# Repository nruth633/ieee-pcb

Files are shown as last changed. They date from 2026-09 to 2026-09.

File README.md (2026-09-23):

# IEEE LED Cube Board

KiCad design for one slice of the LED matrix cube that the University of Denver IEEE
chapter is building as a group project. Three daisy-chained 74HCT595 shift registers drive
24 MMBT3904 low-side switches, which gives eight RGB columns from a five-wire bus (CLK,
DATA, LATCH, BLANK, GND).

Write-up: https://nruth633.github.io/projects/ieee-cube.html

Open `ieee.kicad_pro` in KiCad 10.

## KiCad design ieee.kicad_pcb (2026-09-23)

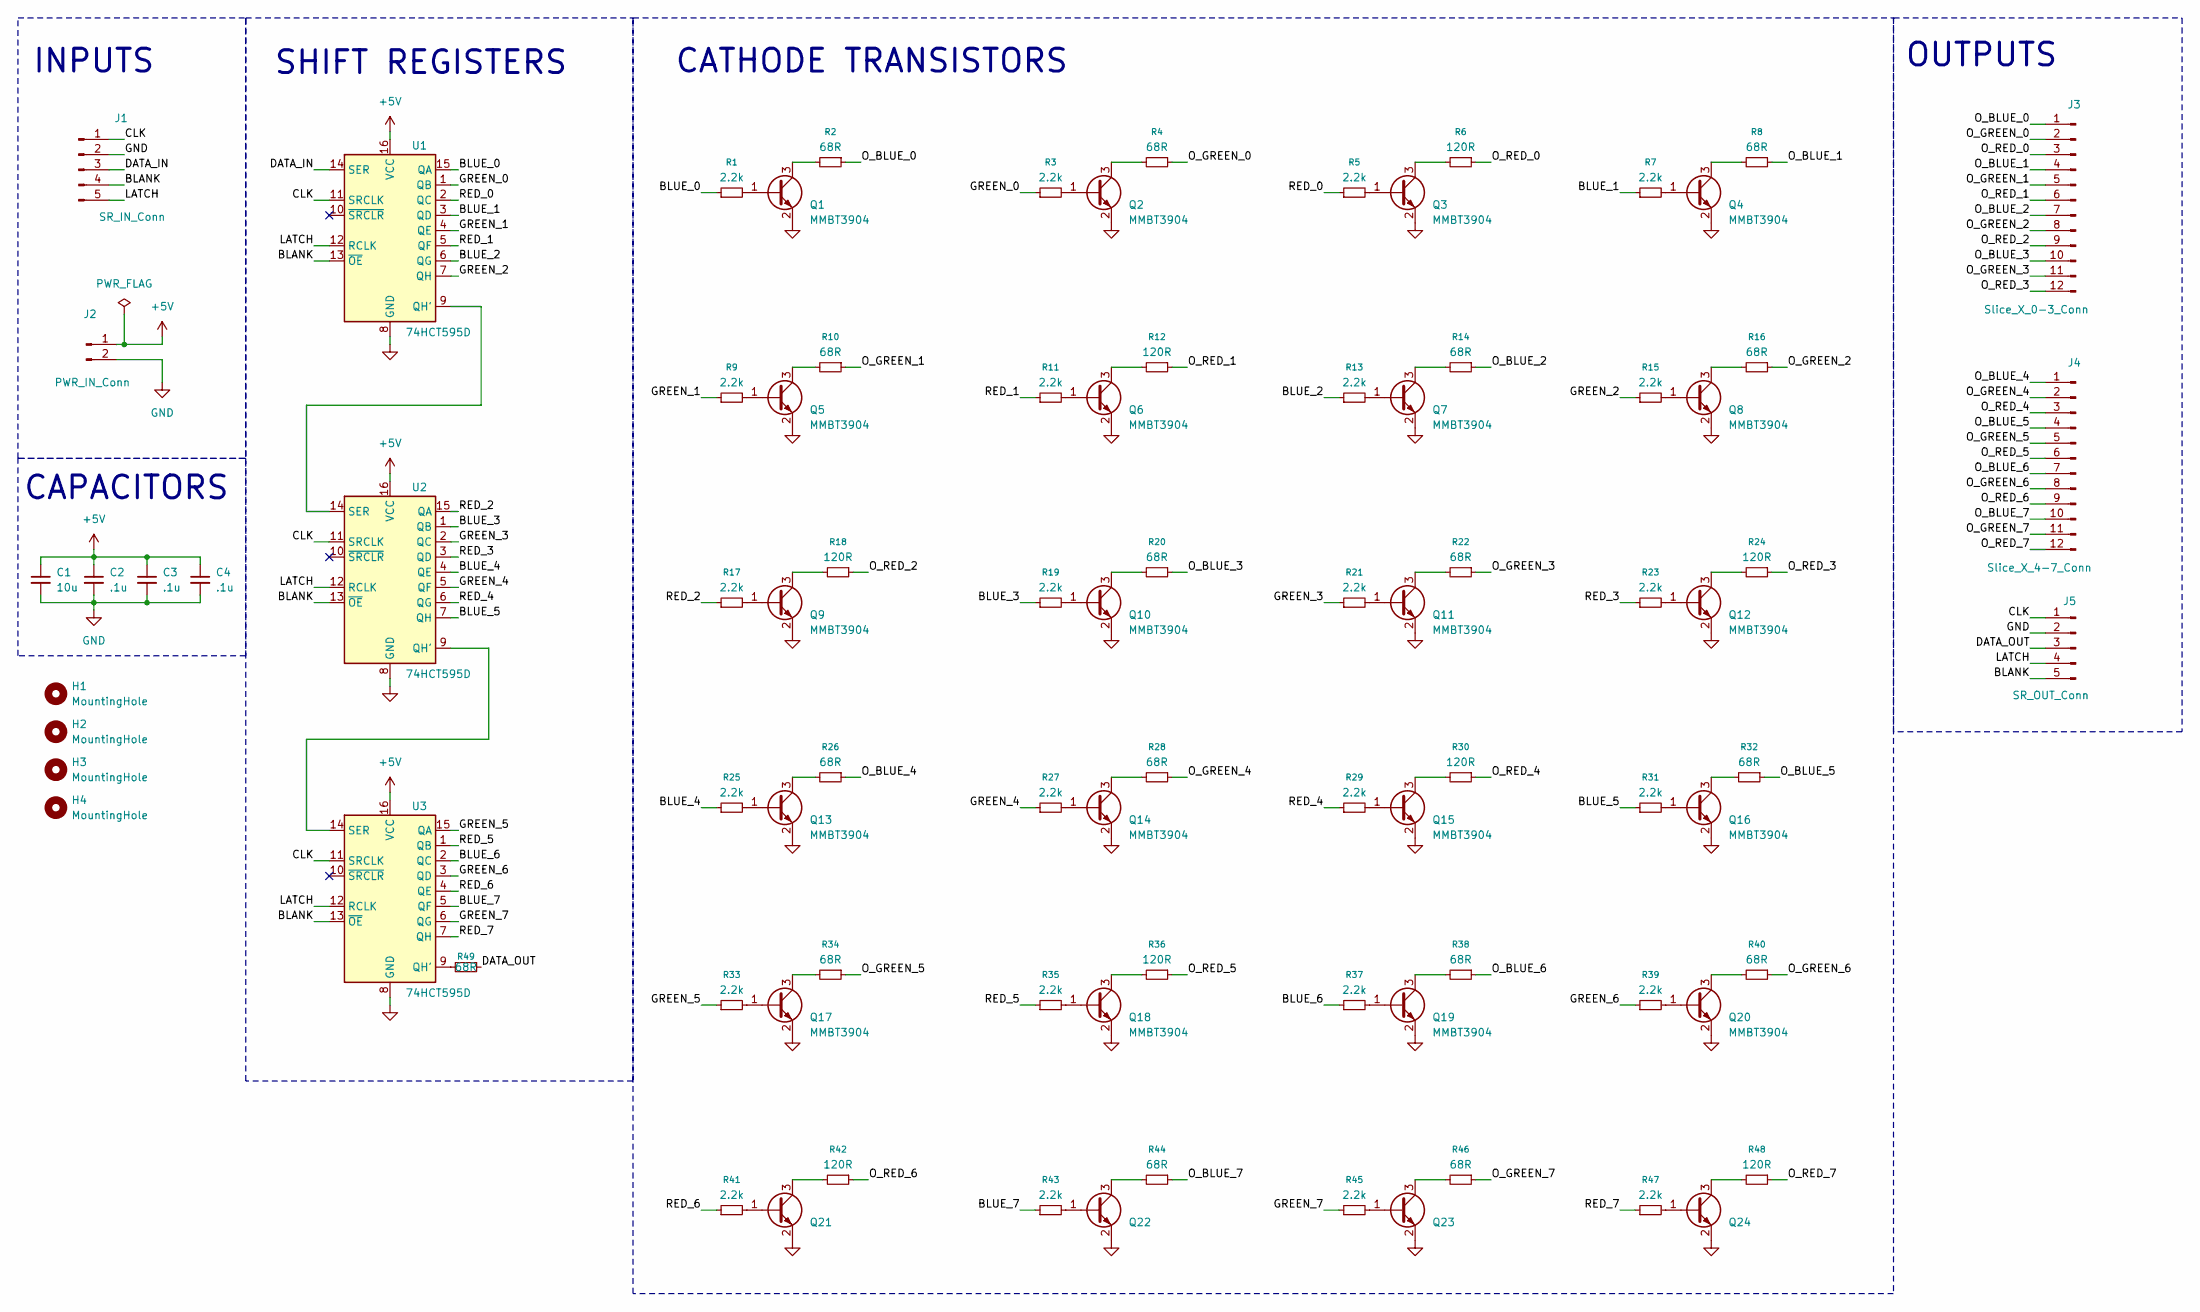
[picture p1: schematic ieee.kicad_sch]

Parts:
C1: 10u; C_0805_2012Metric_Pad1.18x1.45mm_HandSolder; Mfr # MCASL21GBB7106KTNA01
C2, C3, C4: .1u; C_0805_2012Metric_Pad1.18x1.45mm_HandSolder; Mfr # KAF21BR71H104JM
H1, H2, H3, H4: MountingHole; MountingHole_3.2mm_M3
J1: SR_IN_Conn; JST_PH_B5B-PH-K_1x05_P2.00mm_Vertical; Mfr # B5B-PH-K-S(LF)(SN)
J2: PWR_IN_Conn; JST_XH_B2B-XH-A_1x02_P2.50mm_Vertical; Mfr # B2B-XH-A
J3: Slice_X_0-3_Conn; JST_PH_B12B-PH-K_1x12_P2.00mm_Vertical; Mfr # B12B-PH-K-S
J4: Slice_X_4-7_Conn; JST_PH_B12B-PH-K_1x12_P2.00mm_Vertical; Mfr # B12B-PH-K-S
J5: SR_OUT_Conn; JST_PH_B5B-PH-K_1x05_P2.00mm_Vertical; Mfr # B5B-PH-K-S(LF)(SN)
Q1, Q2, Q3, Q4, Q5, Q6, Q7, Q8, Q9, Q10, Q11, Q12, Q13, Q14, Q15, Q16, Q17, Q18, Q19, Q20, Q21, Q22, Q23, Q24: MMBT3904; SOT-23; Mfr # 750-MMBT3904-G
R1, R3, R5, R7, R9, R11, R13, R15, R17, R19, R21, R23, R25, R27, R29, R31, R33, R35, R37, R39, R41, R43, R45, R47: 2.2k; R_0805_2012Metric_Pad1.20x1.40mm_HandSolder; Mfr # 0805W8J0222T5E
R2, R4, R8, R10, R14, R16, R20, R22, R26, R28, R32, R34, R38, R40, R44, R46, R49: 68R; R_0805_2012Metric_Pad1.20x1.40mm_HandSolder; Mfr # 0805W8J0680T5E
R6, R12, R18, R24, R30, R36, R42, R48: 120R; R_0805_2012Metric_Pad1.20x1.40mm_HandSolder; Mfr # RT0805FRE13120RL
U1, U2, U3: 74HCT595D; SOIC-16_3.9x9.9mm_P1.27mm; Mfr # 74HCT595D,118

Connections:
+5V: C1.1, C2.1, C3.1, C4.1, J2.1, U1.16 (VCC), U2.16 (VCC), U3.16 (VCC)
/BLANK: J1.4, J5.5, U1.13 (~OE), U2.13 (~OE), U3.13 (~OE)
/BLUE_0: R1.1, U1.15 (QA)
/BLUE_1: R7.1, U1.3 (QD)
/BLUE_2: R13.1, U1.6 (QG)
/BLUE_3: R19.1, U2.1 (QB)
/BLUE_4: R25.1, U2.4 (QE)
/BLUE_5: R31.1, U2.7 (QH)
/BLUE_6: R37.1, U3.2 (QC)
/BLUE_7: R43.1, U3.5 (QF)
/CLK: J1.1, J5.1, U1.11 (SRCLK), U2.11 (SRCLK), U3.11 (SRCLK)
/DATA_IN: J1.3, U1.14 (SER)
/DATA_OUT: J5.3, R49.1
/GREEN_0: R3.1, U1.1 (QB)
/GREEN_1: R9.1, U1.4 (QE)
/GREEN_2: R15.1, U1.7 (QH)
/GREEN_3: R21.1, U2.2 (QC)
/GREEN_4: R27.1, U2.5 (QF)
/GREEN_5: R33.1, U3.15 (QA)
/GREEN_6: R39.1, U3.3 (QD)
/GREEN_7: R45.1, U3.6 (QG)
/LATCH: J1.5, J5.4, U1.12 (RCLK), U2.12 (RCLK), U3.12 (RCLK)
/O_BLUE_0: J3.1, R2.1
/O_BLUE_1: J3.4, R8.1
/O_BLUE_2: J3.7, R14.1
/O_BLUE_3: J3.10, R20.1
/O_BLUE_4: J4.1, R26.1
/O_BLUE_5: J4.4, R32.1
/O_BLUE_6: J4.7, R38.1
/O_BLUE_7: J4.10, R44.1
/O_GREEN_0: J3.2, R4.1
/O_GREEN_1: J3.5, R10.1
/O_GREEN_2: J3.8, R16.1
/O_GREEN_3: J3.11, R22.1
/O_GREEN_4: J4.2, R28.1
/O_GREEN_5: J4.5, R34.1
/O_GREEN_6: J4.8, R40.1
/O_GREEN_7: J4.11, R46.1
/O_RED_0: J3.3, R6.1
/O_RED_1: J3.6, R12.1
/O_RED_2: J3.9, R18.1
/O_RED_3: J3.12, R24.1
/O_RED_4: J4.3, R30.1
/O_RED_5: J4.6, R36.1
/O_RED_6: J4.9, R42.1
/O_RED_7: J4.12, R48.1
/RED_0: R5.1, U1.2 (QC)
/RED_1: R11.1, U1.5 (QF)
/RED_2: R17.1, U2.15 (QA)
/RED_3: R23.1, U2.3 (QD)
/RED_4: R29.1, U2.6 (QG)
/RED_5: R35.1, U3.1 (QB)
/RED_6: R41.1, U3.4 (QE)
/RED_7: R47.1, U3.7 (QH)
GND: C1.2, C2.2, C3.2, C4.2, J1.2, J2.2, J5.2, Q1.2 (E), Q2.2 (E), Q3.2 (E), Q4.2 (E), Q5.2 (E), Q6.2 (E), Q7.2 (E), Q8.2 (E), Q9.2 (E), Q10.2 (E), Q11.2 (E), Q12.2 (E), Q13.2 (E), Q14.2 (E), Q15.2 (E), Q16.2 (E), Q17.2 (E), Q18.2 (E), Q19.2 (E), Q20.2 (E), Q21.2 (E), Q22.2 (E), Q23.2 (E), Q24.2 (E), U1.8 (GND), U2.8 (GND), U3.8 (GND)
unnamed: Q1.1 (B), R1.2
unnamed: Q1.3 (C), R2.2
unnamed: Q2.1 (B), R3.2
unnamed: Q2.3 (C), R4.2
unnamed: Q3.1 (B), R5.2
unnamed: Q3.3 (C), R6.2
unnamed: Q4.1 (B), R7.2
unnamed: Q4.3 (C), R8.2
unnamed: Q5.1 (B), R9.2
unnamed: Q5.3 (C), R10.2
unnamed: Q6.1 (B), R11.2
unnamed: Q6.3 (C), R12.2
unnamed: Q7.1 (B), R13.2
unnamed: Q7.3 (C), R14.2
unnamed: Q8.1 (B), R15.2
unnamed: Q8.3 (C), R16.2
unnamed: Q9.1 (B), R17.2
unnamed: Q9.3 (C), R18.2
unnamed: Q10.1 (B), R19.2
unnamed: Q10.3 (C), R20.2
unnamed: Q11.1 (B), R21.2
unnamed: Q11.3 (C), R22.2
unnamed: Q12.1 (B), R23.2
unnamed: Q12.3 (C), R24.2
unnamed: Q13.1 (B), R25.2
unnamed: Q13.3 (C), R26.2
unnamed: Q14.1 (B), R27.2
unnamed: Q14.3 (C), R28.2
unnamed: Q15.1 (B), R29.2
unnamed: Q15.3 (C), R30.2
unnamed: Q16.1 (B), R31.2
unnamed: Q16.3 (C), R32.2
unnamed: Q17.1 (B), R33.2
unnamed: Q17.3 (C), R34.2
unnamed: Q18.1 (B), R35.2
unnamed: Q18.3 (C), R36.2
unnamed: Q19.1 (B), R37.2
unnamed: Q19.3 (C), R38.2
unnamed: Q20.1 (B), R39.2
unnamed: Q20.3 (C), R40.2
unnamed: Q21.1 (B), R41.2
unnamed: Q21.3 (C), R42.2
unnamed: Q22.1 (B), R43.2
unnamed: Q22.3 (C), R44.2
unnamed: Q23.1 (B), R45.2
unnamed: Q23.3 (C), R46.2
unnamed: Q24.1 (B), R47.2
unnamed: Q24.3 (C), R48.2
unnamed: U1.9 (QH'), U2.14 (SER)
unnamed: U2.9 (QH'), U3.14 (SER)
unnamed: R49.2, U3.9 (QH')

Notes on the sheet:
INPUTS
CATHODE TRANSISTORS
SHIFT REGISTERS
OUTPUTS
CAPACITORS

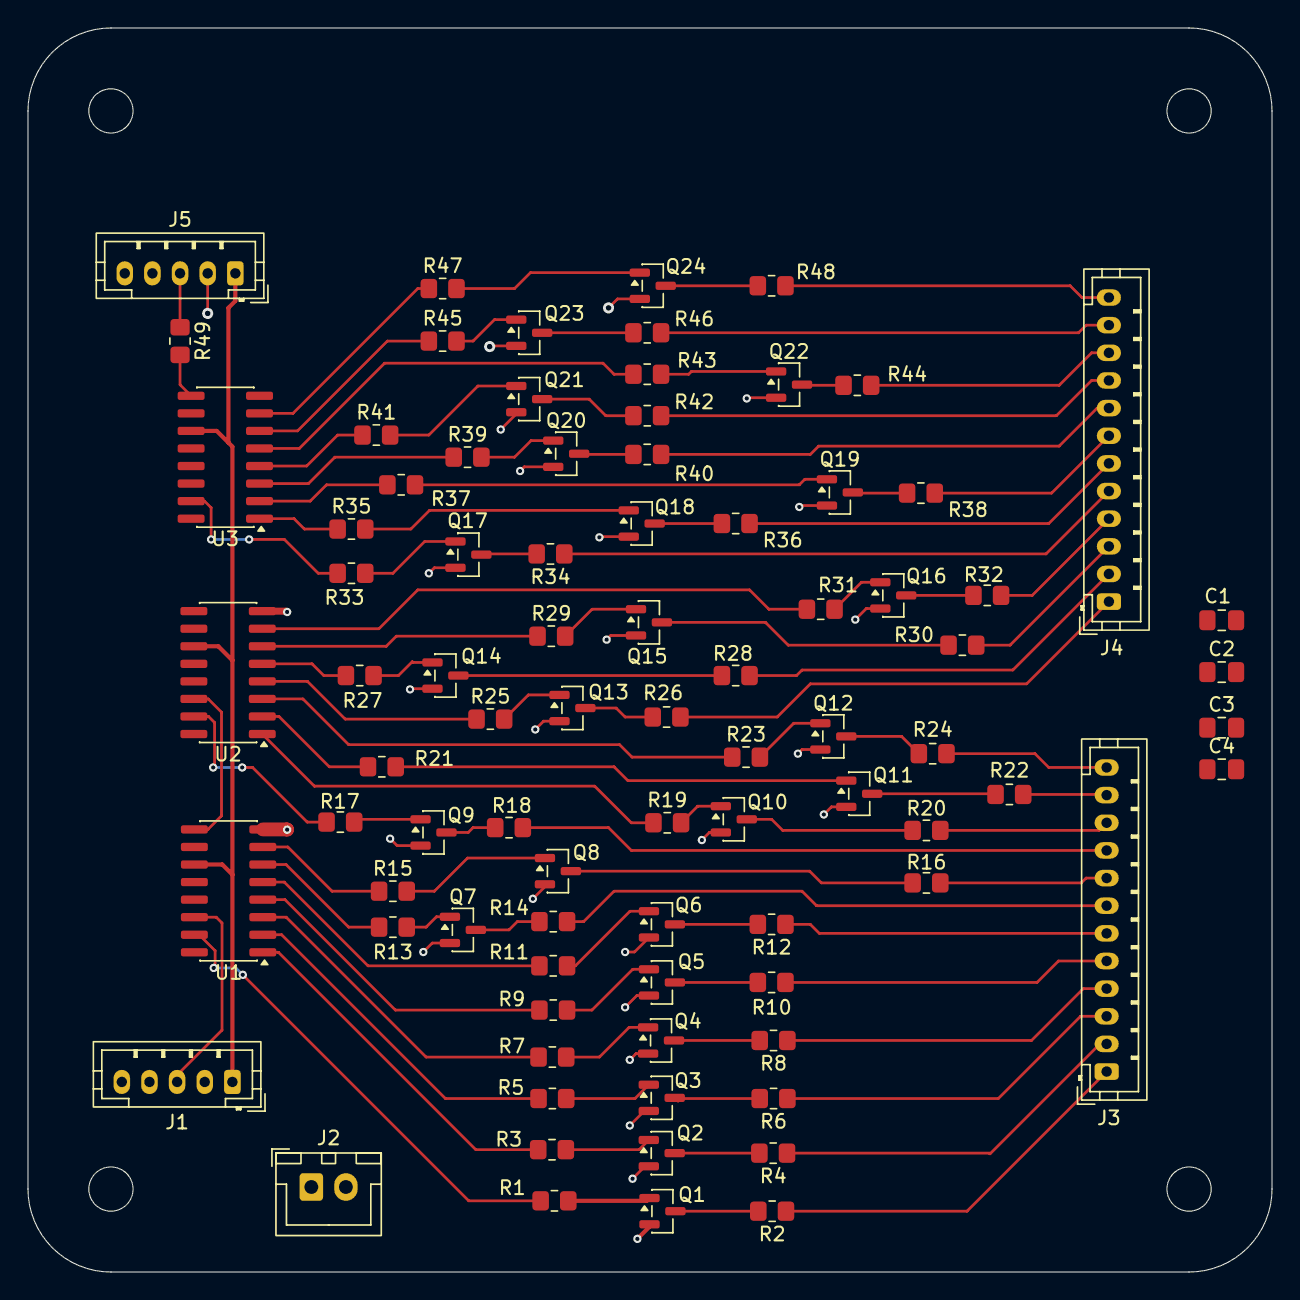
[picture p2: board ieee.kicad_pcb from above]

Board: 2 copper layers, 90.0 x 90.0 mm, 89 parts (0 on the bottom side), 106 nets.
